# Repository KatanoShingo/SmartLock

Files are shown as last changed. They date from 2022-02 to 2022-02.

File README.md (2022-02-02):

  
*Low-cost, scalable, space-saving, and power-saving smart lock project*
====
## 📘Material
### master
- ESP32
- nRF24L01
### slave
- ESP32
- nRF24L01
- CR123A
- MCP1702-3302E
- MG90S
## 📗Schematic
### slave
slave

## 💪Contributing
- If you find a bug, please open Issues.    
- If you have a feature request, please open an issue.    
- If you want to contribute, please send a pull request.    

## 🔓License

[MIT](LICENSE)

## 🐦Authors

 [@shi_k_7](https://twitter.com/shi_k_7)

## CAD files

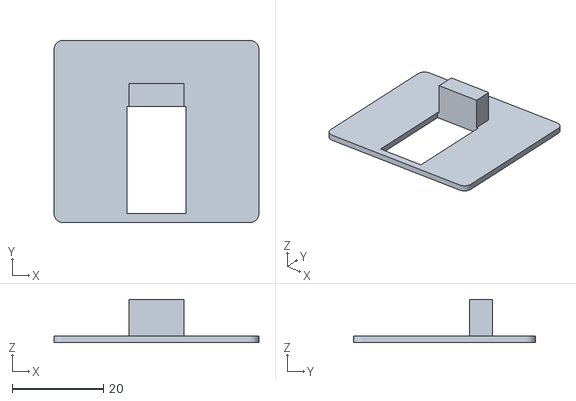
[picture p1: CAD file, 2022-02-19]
stl/batteryCover.stl
45.0 x 40.0 x 9.50

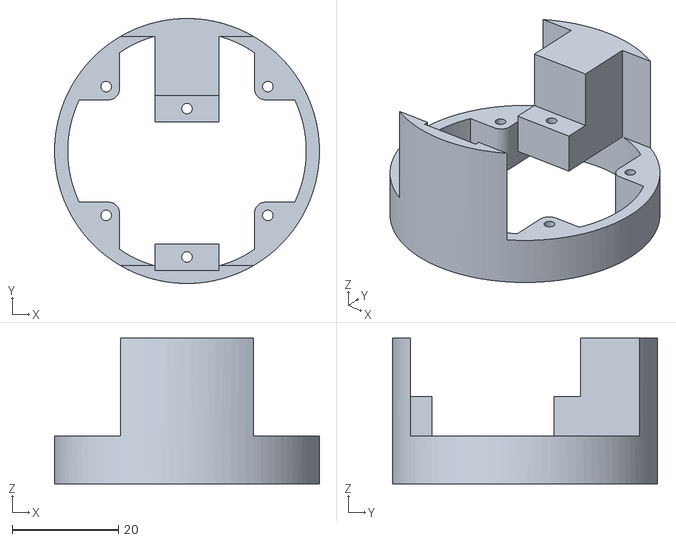
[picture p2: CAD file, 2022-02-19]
stl/body.stl
50.0 x 50.0 x 27.5

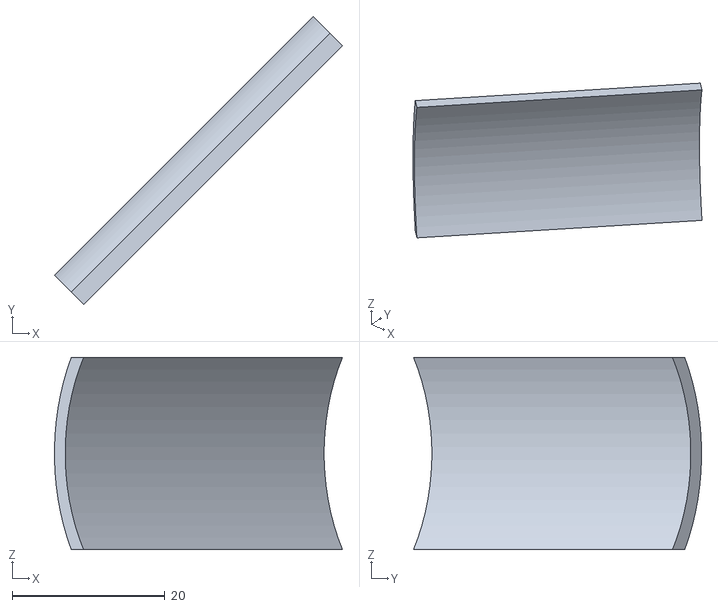
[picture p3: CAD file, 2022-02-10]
stl/wall.stl
37.7 x 37.7 x 25.2

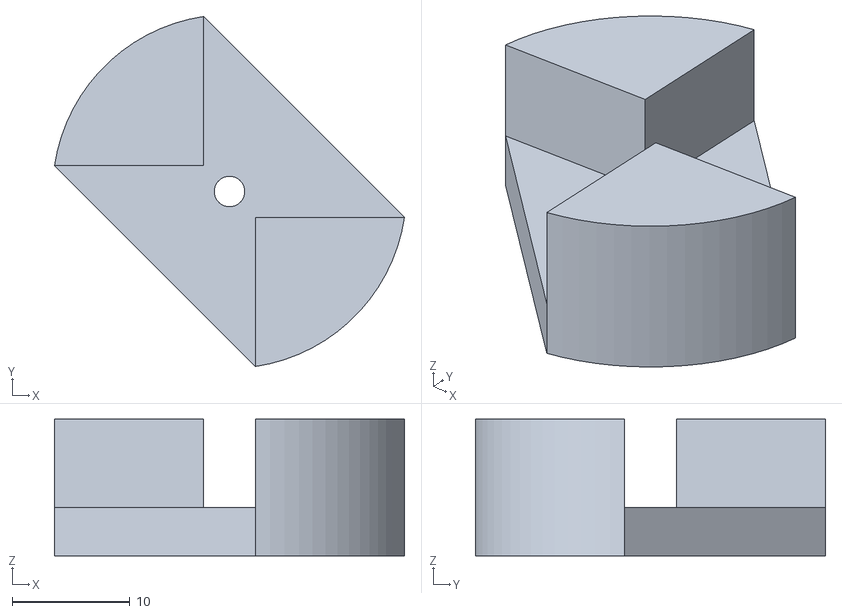
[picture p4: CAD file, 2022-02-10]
stl/thumbturn.stl
29.7 x 29.7 x 11.6

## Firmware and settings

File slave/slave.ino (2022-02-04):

#include <ESP32Servo.h>
#include <nRF24L01.h>

int request;
Servo penguin;
#include <RF24.h>
#define motor 13 
#define switching 5 
#define button 0
RTC_DATA_ATTR int keyStatus;

RF24 radio(4, 22);               // CE,CSNピンの指定
const byte address[6] = "00001";  // データを受信するアドレス

// -1 or +1
void turn(int direction) 
{
  digitalWrite( switching, HIGH );
  for (int angle = 0; angle <= 90; angle++) 
  {
    penguin.write(90+(direction*angle));
    delay(10);
  } 
  delay(500);
  for (int angle = 0; angle <= 90; angle++) 
  {
    penguin.write(90+(direction*(90-angle)));
    delay(10);
  } 
  digitalWrite( switching, LOW );
}

// 初期化
void setup()
{
  // シリアルポートの初期化
  Serial.begin(115200);

  pinMode(button, INPUT);
  pinMode(switching, OUTPUT);
  // MG90の設定
  penguin.attach(motor, 544, 2600);
  
  radio.begin();                    // 無線オブジェクトの初期化
  radio.openReadingPipe(0, address);// データ受信アドレスを指定
  radio.setPALevel(RF24_PA_MIN);    // 出力を最小に
  radio.startListening();           // 受信側として設定
 
  delay(10);
  if(radio.available())
  {
    radio.read(&request, sizeof(request));
    if(request==0)
    {
      if(keyStatus==1)
      {
        keyStatus = -1;
      }
      else
      {
        keyStatus = 1;
      }
      
      turn(keyStatus);
    }
  }          
  
  esp_sleep_enable_timer_wakeup(2 * 1000 * 1000);
  esp_deep_sleep_start();
}

void loop()
{             
}

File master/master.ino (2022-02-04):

#include <nRF24L01.h>
#include <RF24.h>
#include <BlynkSimpleEsp32_BLE.h>
#include <BLEDevice.h>
#include <BLEServer.h>
#include <WiFi.h>
#include <time.h>
#define button 0                        
int request;
RTC_DATA_ATTR int keyStatus;

RF24 radio(4, 22);               // CE,CSNピンの指定
const byte address[6] = "00001";  // データを受信するアドレス

char auth[] = "YourAuthToken";

const char* ssid       = "YOUR_SSID";
const char* password   = "YOUR_PASS";

const char* ntpServer = "pool.ntp.org";
const long  gmtOffset_sec = 3600*9;
const int   daylightOffset_sec = 0;
struct tm timeInfoNow;
hw_timer_t *timer = NULL;

void IRAM_ATTR resetModule() 
{
  ets_printf("reboot\n");
  esp_restart();
}

void setup()
{
  // シリアルポートの初期化
  Serial.begin(115200);

  //WiFiに接続する
  Serial.printf("Connecting to %s ", ssid);
  WiFi.begin(ssid, password);
  while (WiFi.status() != WL_CONNECTED) {
      delay(500);
      Serial.print(".");
  }
  Serial.println(" CONNECTED");

  //時間を初期化
  configTime(gmtOffset_sec, daylightOffset_sec, ntpServer);
  getLocalTime(&timeInfoNow);

  struct tm timeInfoFuture=timeInfoNow;
  timeInfoFuture.tm_mday++;
  timeInfoFuture.tm_hour=0;
  timeInfoFuture.tm_min=0;
  timeInfoFuture.tm_sec=0;
  double wdtTimeout=difftime( mktime(&timeInfoFuture),mktime(&timeInfoNow));
  //不要になったWiFiを切り離す
  WiFi.disconnect(true);
  WiFi.mode(WIFI_OFF);

  pinMode(button, INPUT);

  radio.begin();                  // 無線オブジェクトの初期化
  radio.openWritingPipe(address); // データ送信先のアドレスを指定
  radio.setPALevel(RF24_PA_MIN);  // 出力を最小に
  radio.stopListening();          // 送信側として設定
  
  Blynk.setDeviceName("Blynk");

  Blynk.begin(auth);
  Blynk.run();

  Serial.println("再起動しました");
  Serial.print(wdtTimeout);
  Serial.println("秒後に再起動します");
  timer = timerBegin(0, 80, true);                  //timer 0, div 80
  timerAttachInterrupt(timer, &resetModule, true);  //attach callback
  timerAlarmWrite(timer, wdtTimeout * 1000* 1000, false); //set time in us
  timerAlarmEnable(timer);                          //enable interrupt
}

void loop()
{      
  Blynk.run();
  if(digitalRead(button)==0)
  {
    radio.write(&request, sizeof(request)); 
  }
}

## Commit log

2022-01-18 初期実装のコード追加
2022-01-18 ドアセンサーを削除
2022-01-18 一定時間で閉じる機能削除
2022-01-18 オンライン機能削除
2022-01-18 WiFi情報削除
2022-01-18 ボタンでロックするように変更
2022-01-18 ボタンで開閉するように変更
2022-01-18 動作時以外はdeep sleepするように変更
2022-01-18 インデント修正
2022-01-20 nRF24L01で受信して開閉するように変更
2022-01-20 通信を行うようになったのでファイル名変更
2022-01-21 送信側の追加
2022-01-25 Blynkでスマホで操作出来るように対応
2022-01-25 省電力化の為wakeupを2秒に変更
2022-01-25 readmeに材料の追加
2022-01-31 ライセンス表記の追加
2022-01-31 readme更新
2022-01-31 readmeを更新
2022-02-02 回路図の追加
2022-02-03 時間をwifiで取得するように対応
2022-02-04 毎日0時に再起動して時間を合わせるように対応
2022-02-04 物理鍵とモータが干渉しないように開け閉めを変更
2022-02-05 stlデータの追加
    [case.stl]
2022-02-05 STLデータの画像追加
2022-02-10 stlデータを更新
    [body.stl, case.stl, thumbturn.stl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]
2022-02-14 bodyに基板スペースを確保
    [body.stl]
2022-02-14 stlファイルの画像削除
2022-02-15 土台の厚みを変更
    [body.stl]
2022-02-19 stlの更新
    [batteryCover.stl, body.stl]
